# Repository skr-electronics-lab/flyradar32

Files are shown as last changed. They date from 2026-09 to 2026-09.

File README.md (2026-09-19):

# FlyRadar32

### Autonomous Desktop ADS-B Flight Radar and Avionics Ground Station

FlyRadar32 is a standalone desktop aviation instrument powered by an ESP32 dual-core microcontroller and a 1.8-inch ST7735 SPI display. It aggregates real-time ADS-B transponder telemetry from global flight tracking networks, computes spatial trajectories, and renders a sweeping 60 FPS PPI (Plan Position Indicator) radar display without requiring an external computer or cloud intermediary.

<div align="center">






<p align="center">
  <a href="https://ko-fi.com/skrelectronicslab">
    Support on Ko-fi
  </a>
</p>

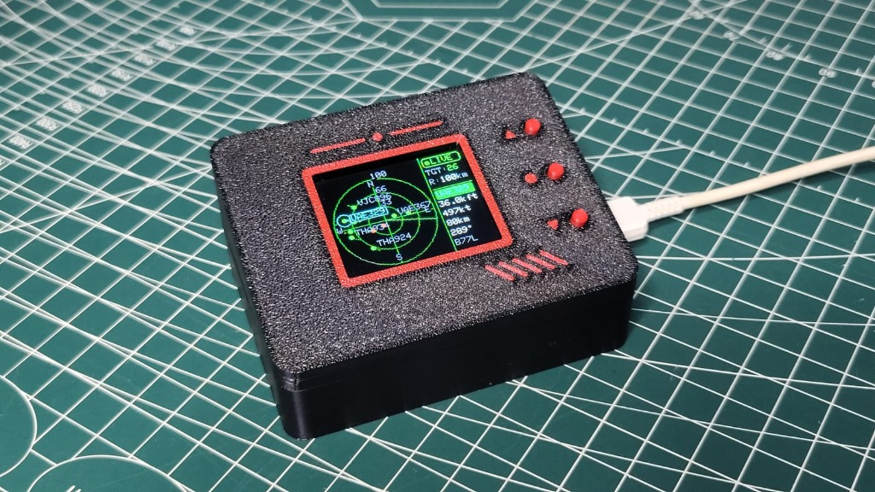
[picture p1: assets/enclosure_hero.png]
FlyRadar32 Desktop Radar Console


</div>

---

## Table of Contents

- [System Architecture](#system-architecture)
- [Key Features](#key-features)
- [Hardware Specification and BOM](#hardware-specification-and-bom)
- [Circuit Diagram and Physical Prototype](#circuit-diagram-and-physical-prototype)
- [3D Printable Enclosure](#3d-printable-enclosure)
- [Embedded Web Dashboard](#embedded-web-dashboard)
- [Firmware Build and Deployment](#firmware-build-and-deployment)
- [First Boot and Captive Portal](#first-boot-and-captive-portal)
- [REST API Specification](#rest-api-specification)
- [GitHub Repository Topics](#github-repository-topics)
- [Author and Support](#author-and-support)
- [License](#license)

---

## System Architecture

FlyRadar32 segregates workloads across both symmetric Xtensa LX6 CPU cores using FreeRTOS tasks to guarantee deterministic screen refresh rates regardless of network latency:

<div align="center">

FlyRadar32 System Architecture

</div>

- **Core 0 (Networking & Telemetry Pipeline):**
  Executes HTTP/TLS REST requests, handles JSON deserialization, runs the automated failover circuit breaker across ADS-B data providers, and serves the embedded web dashboard.
- **Core 1 (Real-Time Graphics Pipeline):**
  Drives the ST7735 display over high-speed SPI (27 MHz). Performs double-buffered polar coordinate projection, renders heading vectors and history trails, and samples tactile push buttons with state debounce logic.

---

## Key Features

- **Live Multi-Target ADS-B Tracking:** Decodes ICAO 24-bit transponder addresses, callsigns, barometric/geometric altitude, ground speed (knots), track heading (degrees), and vertical rate (feet/min).
- **Tri-Tier Provider Redundancy:** Integrates `airplanes.live`, `adsb.lol`, and `OpenSky Network`. An automated circuit breaker detects consecutive network timeouts (3 strikes) and applies a cooldown backoff to prevent API starvation.
- **Precision Polar Radar Graphics:** Plan Position Indicator (PPI) with a continuous sweep line, concentric range rings (5, 10, 25, 50, 100 NM), cardinal compass headings, and target history breadcrumb trails.
- **Self-Contained Embedded Web Dashboard:** Zero-dependency responsive control panel served directly from ESP32 flash with live radar maps, target flight board, weather telemetry, coordinate calibration, Wi-Fi management, and display preferences.
- **Captive Portal Field Deployment:** Launches an autonomous setup Access Point (`FlyRadar32-XXXX`) if configured Wi-Fi credentials fail, automatically redirecting connected mobile or desktop browsers to the provisioning console.
- **Non-Volatile Configuration Memory:** Home coordinates, range limits, display brightness, screen themes, and API credentials persist across power cycles in ESP32 Non-Volatile Storage (NVS).

---

## Hardware Specification and BOM

| Component | Specification | Quantity | Reference Source |
|---|---|---|---|
| Microcontroller | ESP32-WROOM-32 (30-Pin DevKit, 4MB Flash) | 1 | Espressif Systems |
| Display | 1.8" TFT ST7735 (128x160 RGB, 4-Wire SPI) | 1 | Black-Tab / Red-Tab |
| User Input | 6x6x3.8mm Momentary Tactile Push Buttons | 3 | SPST Through-Hole |
| Enclosure | 3-Piece Precision FDM Chassis (PETG / PLA) | 1 Set | [enclosure/](enclosure/) |
| Power Source | 5V USB-C or Micro-USB (500mA minimum) | 1 | Standard USB Port |

---

## Circuit Diagram and Physical Prototype

### Live Hardware Prototype

<div align="center">

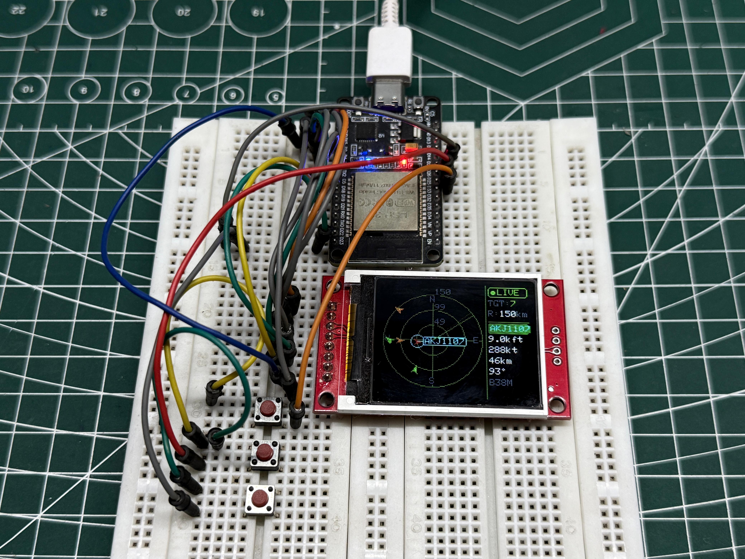
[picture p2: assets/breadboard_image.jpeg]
FlyRadar32 Live Breadboard Prototype


*FlyRadar32 standalone hardware tracking active aviation target AKJ1107 (Boeing 737 MAX 8) on a 1.8" ST7735 SPI display.*

</div>

### Schematic Circuit Diagram

<div align="center">

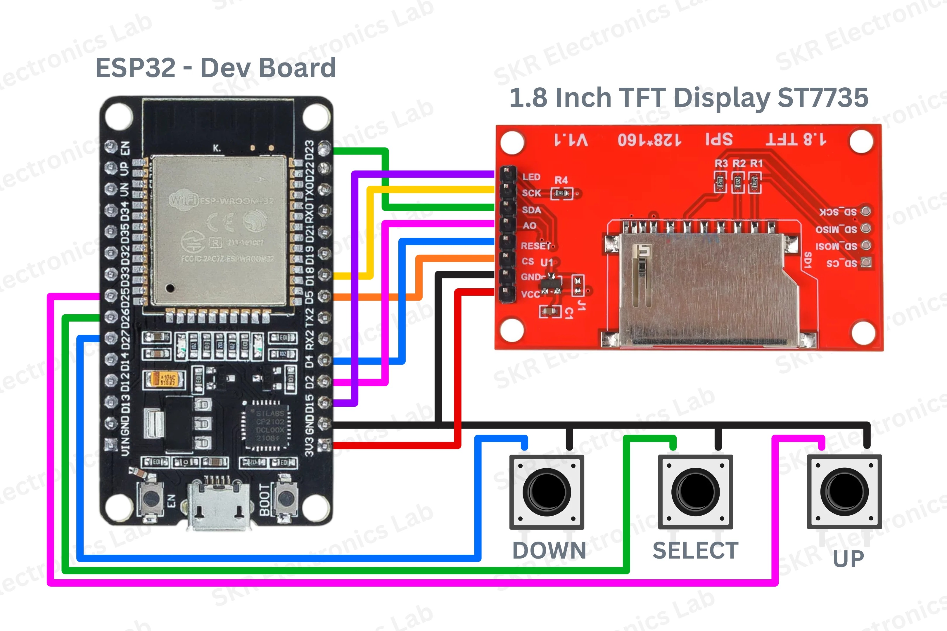
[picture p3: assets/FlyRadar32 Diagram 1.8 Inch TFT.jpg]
FlyRadar32 Circuit Diagram


</div>

### Pinout Mapping

| Function | ESP32 GPIO | Peripheral Pin | Description |
|---|---|---|---|
| Display SCLK | GPIO 18 | SCK / CLK | Hardware VSPI Clock (27 MHz) |
| Display MOSI | GPIO 23 | SDA / DIN | Hardware VSPI Data Line |
| Display CS | GPIO 5 | CS | Chip Select (Active Low) |
| Display DC | GPIO 2 | DC / AO | Data / Command Select |
| Display RST | GPIO 4 | RES / RESET | Hardware Reset Pulse |
| Display BL | GPIO 15 | BL / LED | Hardware LEDC PWM Backlight Dimming (5,000 Hz, 8-Bit) |
| Display VCC | VIN (5V) / 3V3 | VCC | Display Logic and Backlight Supply |
| Display GND | GND | GND | Common Circuit Ground |
| Button UP | GPIO 25 | Pin 1 to GPIO, Pin 2 to GND | Cycle target aircraft / Long-press: Live Weather |
| Button DOWN | GPIO 26 | Pin 1 to GPIO, Pin 2 to GND | Cycle target aircraft / Long-press: Flight List |
| Button SELECT | GPIO 27 | Pin 1 to GPIO, Pin 2 to GND | Short: Flight Detail / Long: Settings / Dual UP+DOWN: Weather |

> **Strapping Pin Notice:** Do not connect pull-down loads or switches to GPIO 0, GPIO 12, or GPIO 15 that force unexpected boot logic levels.

---

## 3D Printable Enclosure

The desktop enclosure features an ergonomic 15-degree instrument slant, internal snap-latch joints, zero exterior screws, and anti-fallout button actuators.

All 3D models and print documentation are located in the [enclosure/](enclosure/) directory:

<div align="center">

| Internal Seating | Transparent Assembly |
|:---:|:---:|
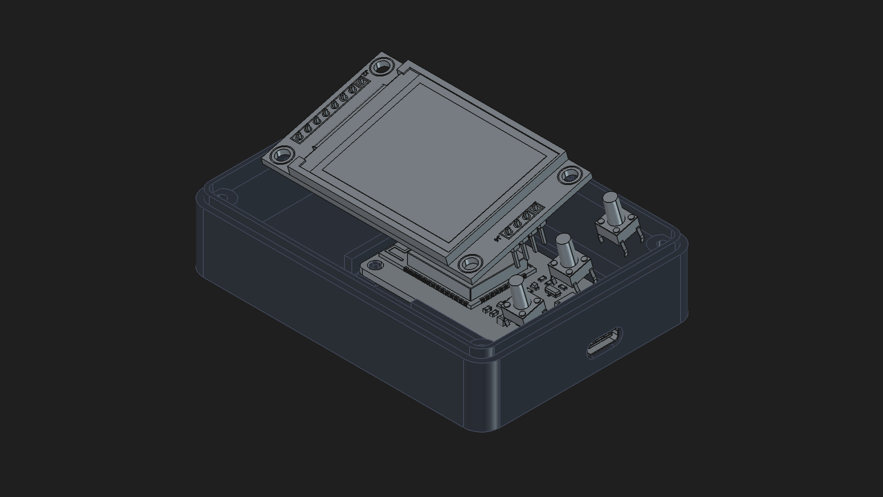
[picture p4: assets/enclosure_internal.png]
Internal Seating
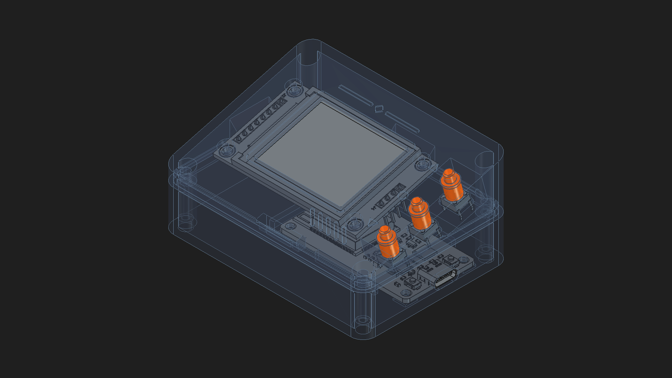
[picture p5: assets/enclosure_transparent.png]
Transparent Assembly
|  |  |

</div>

### Printable Files

- [`enclosure/flyradar32_shell.stl`](enclosure/flyradar32_shell.stl) — Bottom chassis with ESP32 board rails and USB collar.
- [`enclosure/flyradar32_lid.stl`](enclosure/flyradar32_lid.stl) — Top bezel with 15° instrument tilt and display aperture.
- [`enclosure/flyradar32_button_caps.stl`](enclosure/flyradar32_button_caps.stl) — 3x tactile actuator keycaps with retention lips.
- [`enclosure/FlyRadar32_Enclosure.FCStd`](enclosure/FlyRadar32_Enclosure.FCStd) — Master parametric CAD file (FreeCAD).

### Print Parameters

- **Layer Height:** 0.20 mm (0.16 mm for keycaps)
- **Walls / Perimeters:** 3
- **Infill:** 20% Gyroid or Grid
- **Material:** PETG or PLA
- **Supports:** None required (All geometries self-supporting <= 45°)

---

## Embedded Web Dashboard

FlyRadar32 serves an asynchronous, zero-dependency web interface directly from internal LittleFS flash storage.

<div align="center">

| Live Radar Scope | Air Traffic Flight Board |
|:---:|:---:|
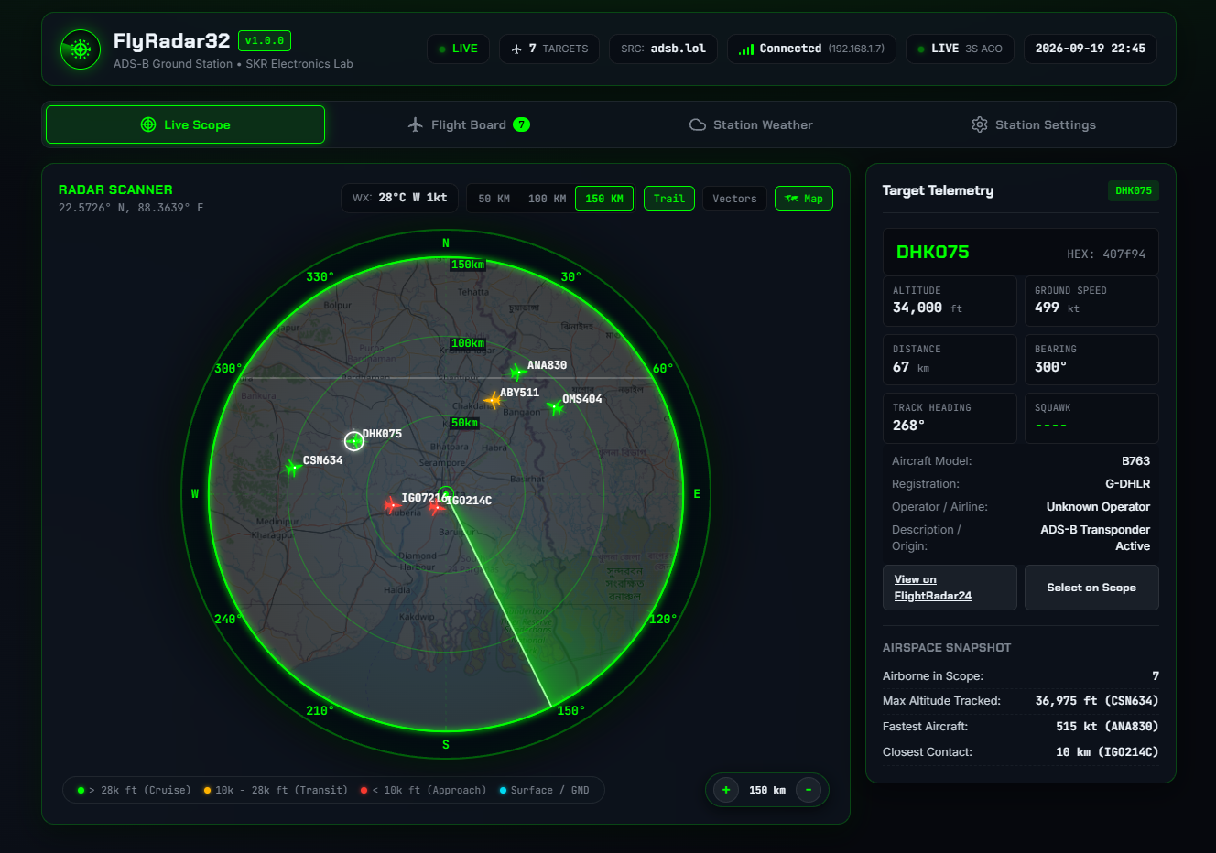
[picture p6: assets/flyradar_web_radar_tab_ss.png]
Live Radar Scope
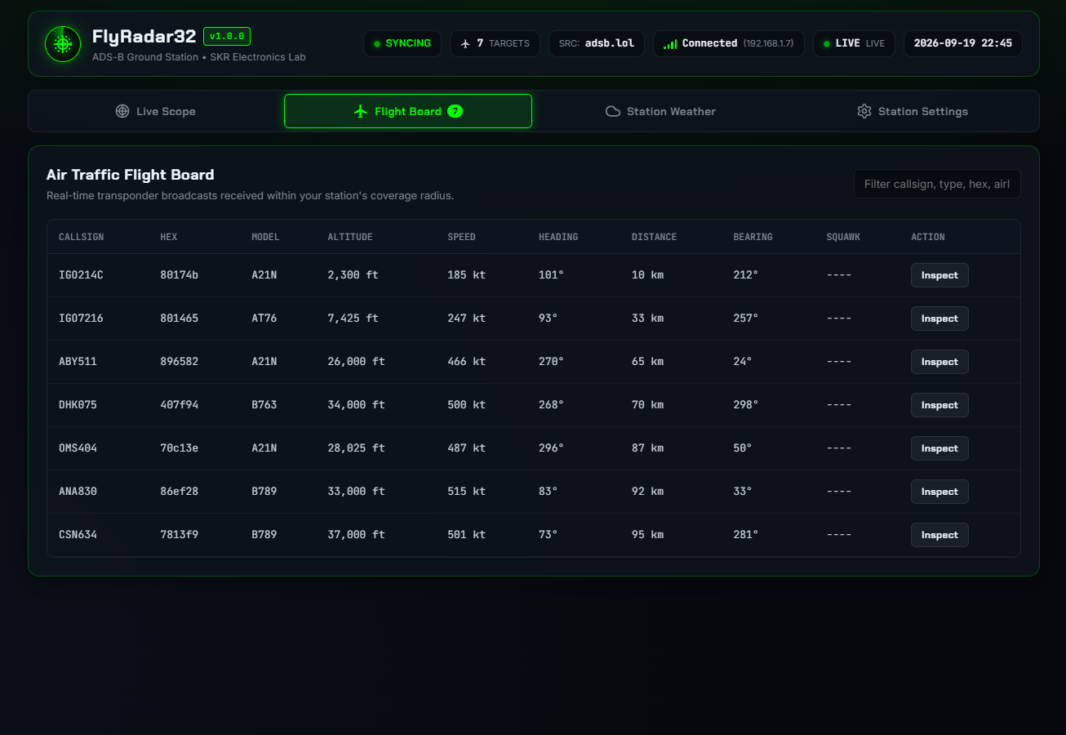
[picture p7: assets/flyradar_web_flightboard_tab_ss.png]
Air Traffic Flight Board
|  |  |

| Station Weather | Station Settings |
|:---:|:---:|
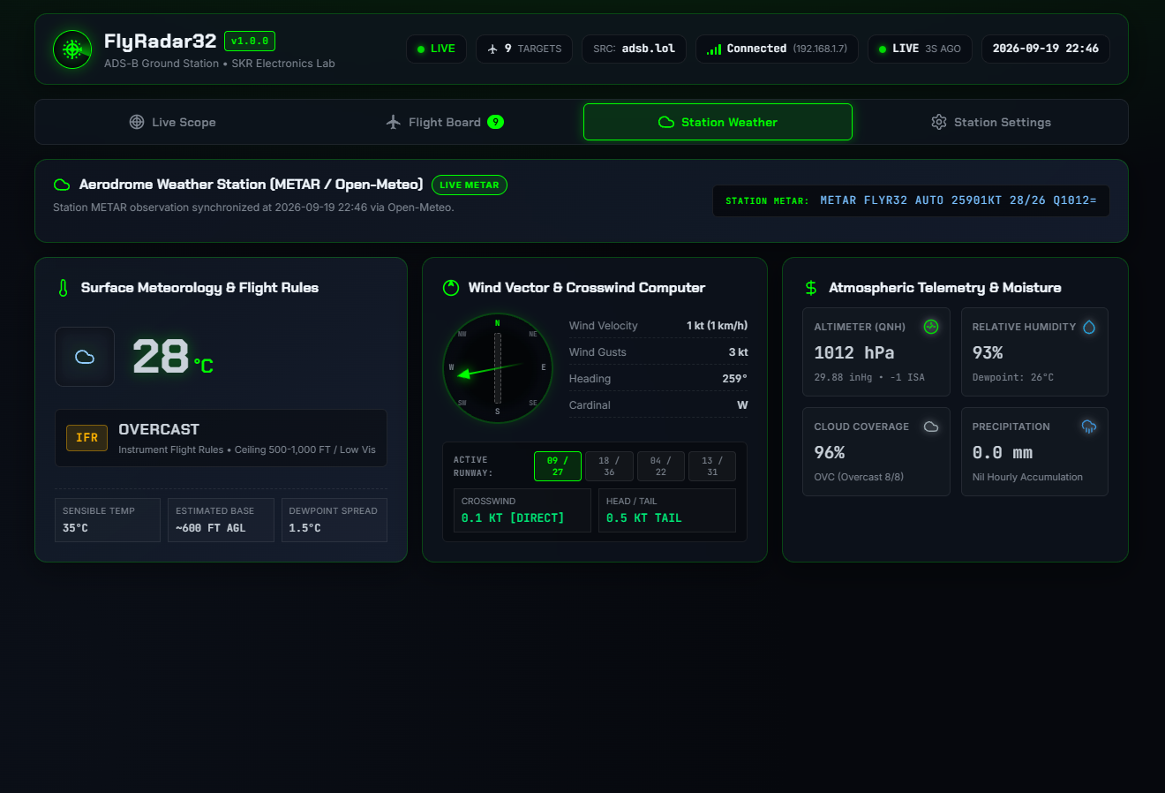
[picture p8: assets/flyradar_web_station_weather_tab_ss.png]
Station Weather
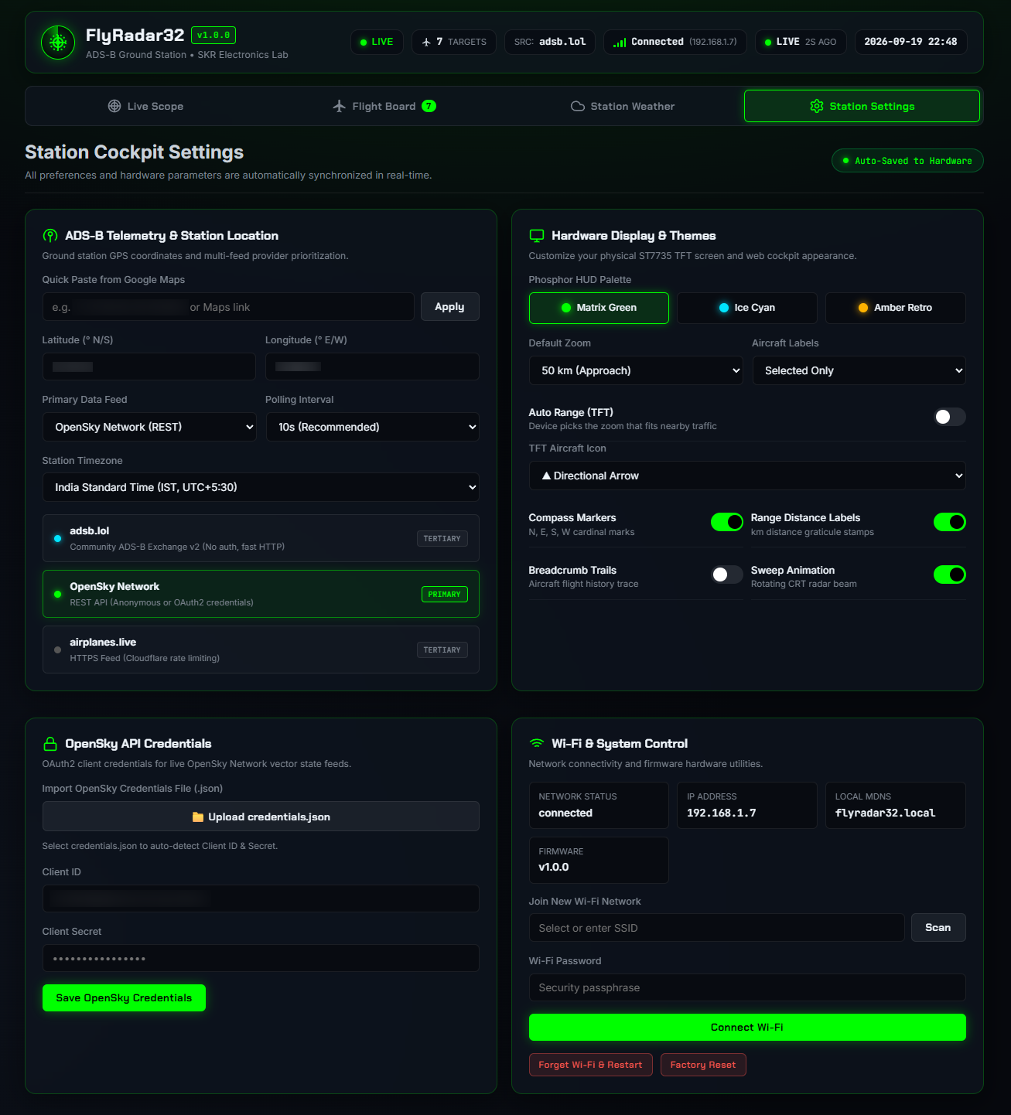
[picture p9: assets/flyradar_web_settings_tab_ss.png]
Station Settings
|  |  |

</div>

- **Live Scope:** Real-time canvas radar scope displaying aircraft positions, heading vectors, altitude color bands, and range scaling.
- **Flight Board:** Tabular air traffic ledger with callsign search, hex code, altitude, speed, heading, and distance sorting.
- **Station Weather:** Live local barometric and meteorological telemetry report.
- **Station Settings:** Coordinate calibration, Wi-Fi network switching, refresh intervals, and display themes.

---

## Firmware Build and Deployment

PlatformIO automatically compresses web assets from `data/` into Gzip byte arrays during compilation.

```bash
# Clone the repository
git clone https://github.com/skrelectronicslab/flyradar32.git
cd flyradar32

# Compile firmware
pio run

# Flash firmware over USB
pio run --target upload

# Open serial telemetry monitor (115200 baud)
pio run --target monitor
```

---

## First Boot and Captive Portal

1. **Power-On:** If no Wi-Fi credentials are saved, the device hosts an Access Point named `FlyRadar32-XXXX` (passphrase: `radar1234`).
2. **Setup Portal:** Connect to the AP from a mobile phone or laptop. The browser automatically navigates to `http://192.168.4.1`.
3. **Configure:** Select your Wi-Fi SSID, enter the password, and set your observer coordinates.
4. **Operation:** The device connects to your network, displays its assigned IP address on the screen, and starts tracking live aircraft.

---

## REST API Specification

FlyRadar32 exposes a lightweight HTTP REST API for integration into Home Assistant, Node-RED, or custom telemetry dashboards:

| Method | Endpoint | Description | Sample Output / Payload |
|---|---|---|---|
| `GET` | `/api/status` | Current radar telemetry and aircraft list | `{"uptime":3600,"wifi":"OK","aircraft_count":12,"targets":[...]}` |
| `GET` | `/api/config` | Read active system parameters | `{"lat":37.7749,"lon":-122.4194,"range":25,"theme":0}` |
| `POST` | `/api/config` | Update system parameters | `{"lat":51.5074,"lon":-0.1278,"range":50}` |
| `GET` | `/api/wifi/scan`| Scan for 2.4GHz Wi-Fi networks | `[{"ssid":"HomeNet","rssi":-58,"secure":true}]` |
| `POST` | `/api/wifi/connect`| Save Wi-Fi credentials and connect | `{"ssid":"HomeNet","password":"secretpassword"}` |
| `POST` | `/api/restart` | Issue software reboot | `{"status":"restarting"}` |

---

## GitHub Repository Topics

Add the following tags in your GitHub repository settings under **About -> Topics**:

```text
esp32, ads-b, flight-radar, aviation, radar-display, st7735, freertos, platformio, embedded-systems, cplusplus, 3d-printing, freecad, opensky-network, iot, open-source-hardware
```

---

## Author and Support

FlyRadar32 is designed and developed by **Raihan (SK Raihan)**.

- **Organization:** SKR Electronics Lab / SKR Projects Hub
- **YouTube:** [@skr_electronics_lab](https://youtube.com/@skr_electronics_lab)
- **Instagram:** [@skr_electronics_lab](https://instagram.com/skr_electronics_lab)
- **X (Twitter):** [@skrelectronics](https://twitter.com/skrelectronics)
- **Email:** `skrelectronicslab@gmail.com`

If you enjoy this open-source project and want to support ongoing development, consider buying a coffee on Ko-fi:

<div align="center">

Support on Ko-fi (https://ko-fi.com/skrelectronicslab)

</div>

---

## License
 
 This project is licensed under the [Creative Commons Attribution-NonCommercial-NoDerivatives 4.0 International License (CC BY-NC-ND 4.0)](LICENSE).
 
 - **Personal & Educational Use:** Free to build, 3D-print, flash firmware, and operate physical FlyRadar32 units for personal non-commercial hobbyist use.
 - **No Rebranding / No Derivatives:** You may not modify the design, source code, or CAD models and redistribute them claiming them as your own original work.
 - **Non-Commercial:** Commercial manufacturing, sale of pre-assembled units, paid kits, or commercial monetization without prior explicit written authorization is strictly prohibited.
 - **Attribution:** Creator credit to **SK Raihan (SKR Electronics Lab)** must be preserved on all forks and physical builds.

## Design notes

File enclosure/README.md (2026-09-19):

# FlyRadar32 3D Printable Enclosure

Snap-fit desktop console enclosure for the FlyRadar32 standalone ADS-B ground station.

---

<div align="center">

FlyRadar32 3D Printable Console

</div>

---

## Printable Files

The complete enclosure consists of three printable STL files designed for zero-support FDM printing:

| File | Description | Material | Infill | Supports |
|---|---|---|---|---|
| [`flyradar32_shell.stl`](flyradar32_shell.stl) | Bottom chassis with ESP32 mounting rails & USB port | PLA / PETG | 20% | None |
| [`flyradar32_lid.stl`](flyradar32_lid.stl) | Top bezel with 15° desktop tilt & display frame | PLA / PETG | 20% | None |
| [`flyradar32_button_caps.stl`](flyradar32_button_caps.stl) | 3x tactile button actuator keycaps | PLA / PETG | 100% | None |

Master CAD Source: [`FlyRadar32_Enclosure.FCStd`](FlyRadar32_Enclosure.FCStd) (FreeCAD).

---

## Hardware Fit & Assembly

<div align="center">

| Internal Seating | Transparent CAD Assembly |
|:---:|:---:|
| Internal Seating | Transparent Assembly |

</div>

### Quick Print Settings

- **Layer Height:** 0.20 mm (0.16 mm for keycaps)
- **Perimeters / Walls:** 3
- **Infill:** 20% Gyroid or Grid
- **Supports:** None needed (all overhangs <= 45°)
- **Orientation:**
  - `flyradar32_shell.stl`: Flat on bottom
  - `flyradar32_lid.stl`: Face-down on print bed
  - `flyradar32_button_caps.stl`: Flange down

### Assembly

1. Drop the 3 button keycaps into the underside of the lid through the switch holes (the retaining flanges keep them from falling out).
2. Seat the 1.8" ST7735 display into the lid frame.
3. Slide the ESP32 into the bottom shell rails and push onto the 4 alignment pins.
4. Snap the lid onto the bottom shell — the internal snap clips lock firmly without screws or glue.

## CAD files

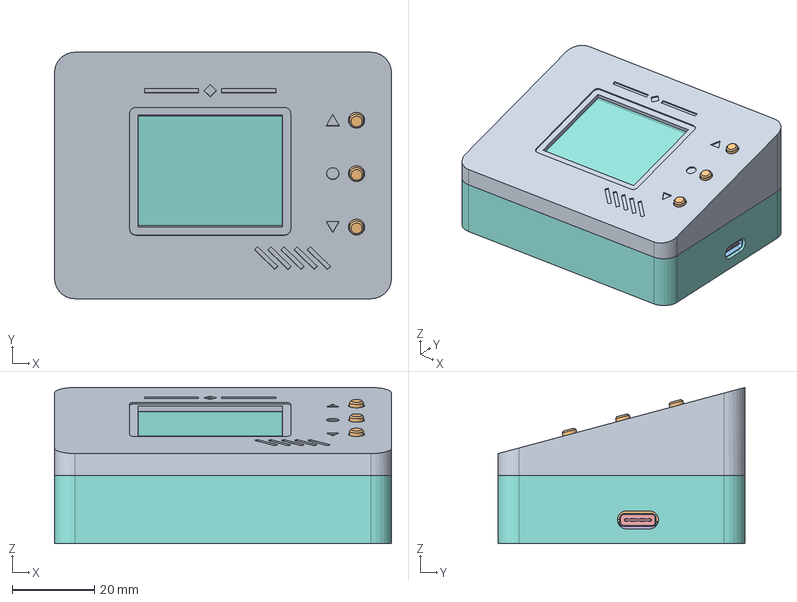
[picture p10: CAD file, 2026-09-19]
enclosure/FlyRadar32_Enclosure.FCStd
82.0 x 60.0 x 38.0 mm
esp32_Wroom_30pins_C-Type
esp32_Wroom_30pins_C-Type001
esp32_Wroom_30pins_C-Type002
esp32_Wroom_30pins_C-Type003
esp32_Wroom_30pins_C-Type004
esp32_Wroom_30pins_C-Type005
esp32_Wroom_30pins_C-Type006
esp32_Wroom_30pins_C-Type007
esp32_Wroom_30pins_C-Type008
esp32_Wroom_30pins_C-Type009
esp32_Wroom_30pins_C-Type010
esp32_Wroom_30pins_C-Type011
esp32_Wroom_30pins_C-Type012
esp32_Wroom_30pins_C-Type013
esp32_Wroom_30pins_C-Type014
esp32_Wroom_30pins_C-Type015
esp32_Wroom_30pins_C-Type016
esp32_Wroom_30pins_C-Type017
esp32_Wroom_30pins_C-Type018
esp32_Wroom_30pins_C-Type019
esp32_Wroom_30pins_C-Type020
esp32_Wroom_30pins_C-Type021
esp32_Wroom_30pins_C-Type022
esp32_Wroom_30pins_C-Type023
esp32_Wroom_30pins_C-Type024
esp32_Wroom_30pins_C-Type025
esp32_Wroom_30pins_C-Type026
esp32_Wroom_30pins_C-Type027
esp32_Wroom_30pins_C-Type028
esp32_Wroom_30pins_C-Type029
esp32_Wroom_30pins_C-Type030
esp32_Wroom_30pins_C-Type031
esp32_Wroom_30pins_C-Type032
esp32_Wroom_30pins_C-Type033
esp32_Wroom_30pins_C-Type034
esp32_Wroom_30pins_C-Type035
esp32_Wroom_30pins_C-Type036
esp32_Wroom_30pins_C-Type037
esp32_Wroom_30pins_C-Type038
esp32_Wroom_30pins_C-Type039
esp32_Wroom_30pins_C-Type040
esp32_Wroom_30pins_C-Type041
esp32_Wroom_30pins_C-Type042
esp32_Wroom_30pins_C-Type043
esp32_Wroom_30pins_C-Type044
esp32_Wroom_30pins_C-Type045
esp32_Wroom_30pins_C-Type046
esp32_Wroom_30pins_C-Type047
esp32_Wroom_30pins_C-Type048
esp32_Wroom_30pins_C-Type049
esp32_Wroom_30pins_C-Type050
esp32_Wroom_30pins_C-Type051
esp32_Wroom_30pins_C-Type052
esp32_Wroom_30pins_C-Type053
esp32_Wroom_30pins_C-Type054
esp32_Wroom_30pins_C-Type055
esp32_Wroom_30pins_C-Type056
esp32_Wroom_30pins_C-Type057
esp32_Wroom_30pins_C-Type058
esp32_Wroom_30pins_C-Type059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

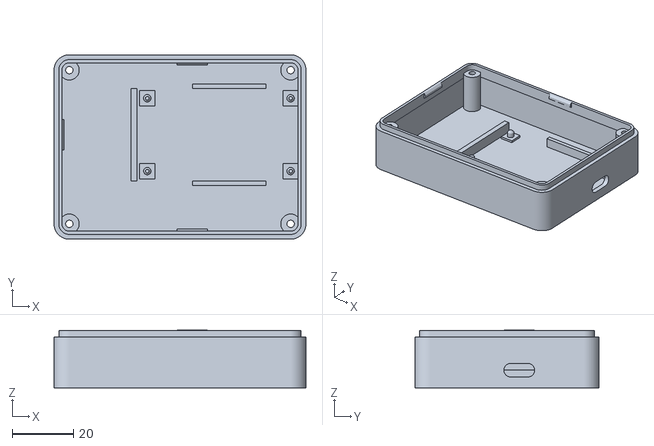
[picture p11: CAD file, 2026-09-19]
enclosure/flyradar32_shell.stl
82.0 x 60.0 x 18.8

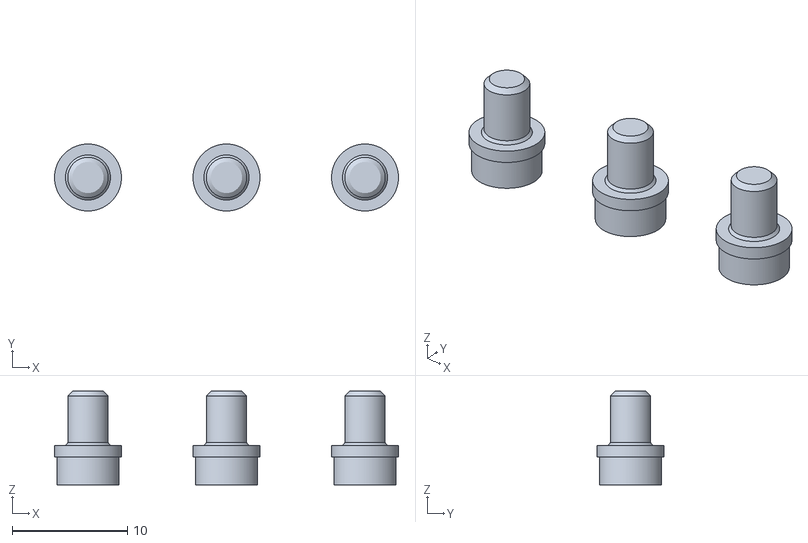
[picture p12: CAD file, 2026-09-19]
enclosure/flyradar32_button_caps.stl
29.8 x 5.80 x 8.10

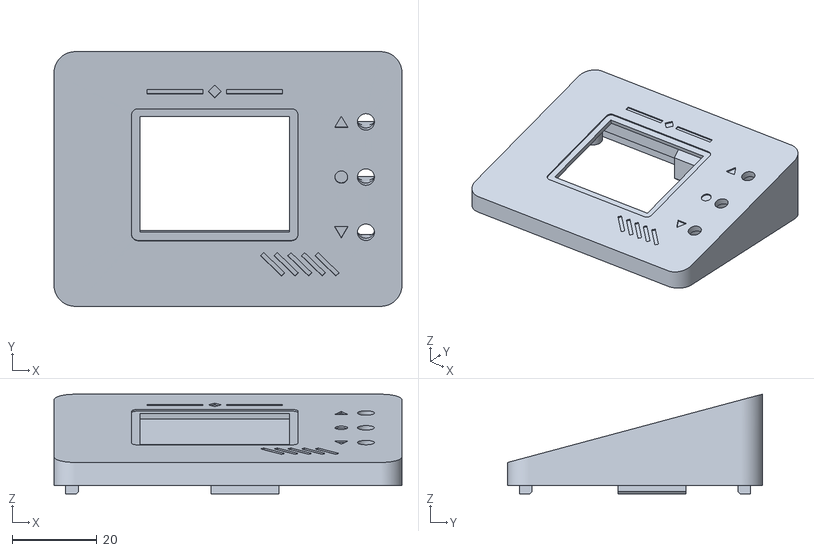
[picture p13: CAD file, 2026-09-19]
enclosure/flyradar32_lid.stl
82.0 x 60.0 x 23.5

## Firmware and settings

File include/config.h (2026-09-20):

#pragma once
#include <Arduino.h>

// ============================================================
//  DISPLAY PINS (ST7735, 128x160 native panel)
//  6-pin: SCL→18, SDA→23, RES→4, DC→2, CS→5, BL→15
// ============================================================
#define TFT_CS    5
#define TFT_RST   4
#define TFT_DC    2
#define TFT_BLK   15
#define TFT_SCLK  18
#define TFT_MOSI  23

// ============================================================
//  ORIENTATION
//  ------------------------------------------------------------
//  The ST7735 panel is *physically* 128 px wide x 160 px tall
//  (that native size is what TFT_WIDTH/TFT_HEIGHT in
//  platformio.ini describe, and must never change — it's what
//  the controller's init sequence was written for).
//
//  Landscape mode is achieved purely by ROTATING that native
//  panel with TFT_ROTATION below. TFT_eSPI swaps width/height
//  for you once you rotate — so from this point on, SCREEN_W /
//  SCREEN_H below are the *logical* (already-rotated) canvas
//  size, and EVERYTHING in the firmware (LVGL resolution, the
//  TFT_eSprite radar canvas, and every layout constant) is
//  derived from these two numbers and nothing else. That is
//  the fix for the old "right side cut off ~40%" bug: previously
//  SCREEN_W/SCREEN_H stayed at the portrait 128x160 values while
//  only the physical rotation changed, so LVGL kept thinking the
//  panel was 128 wide and never drew (160-128)=32 of the 160
//  physical columns, AND the radar sprite was allocated
//  128(w) x 160(h) and pushed onto a panel that was now
//  addressed as 160(w) x 128(h) — a shape mismatch that made
//  the driver's address window wrap/clip, which combined with
//  the old circle being centered on x=64 of what is now the
//  left ~40% of a 160-wide panel, is exactly why it looked like
//  "40% cut off on the right". Fixing SCREEN_W/SCREEN_H to the
//  true rotated size and re-deriving every constant from them
//  removes the mismatch entirely.
//
//  If the image comes up mirrored/upside-down for your specific
//  panel wiring, change TFT_ROTATION to 3 (the only other valid
//  landscape rotation for ST7735) — nothing else needs to change.
// ============================================================
#define TFT_ROTATION 3

#define SCREEN_W  160
#define SCREEN_H  128

// ============================================================
//  BUTTON PINS  (deliberately NOT GPIO0 - that pin is the boot-mode
//  strap; holding it low at power-on/reset forces the download
//  bootloader instead of your app)
// ============================================================
#define BTN_UP      25
#define BTN_DOWN    27
#define BTN_SELECT  26

#define LONG_PRESS_MS   700
#define DEBOUNCE_MS     20

// Watchdog: the Arduino core's Task WDT already exists (5 s idle timeout);
// loop() subscribes to it, so a hung loop triggers a clean reboot.
// (esp_task_wdt_reset() runs at the top of every loop() pass.)
#define WDT_TIMEOUT_S 15

// Backlight PWM runs on GPIO15 (TFT_BLK). If the screen dims INVERTED
// (25% looks brighter than 100%), flip BACKLIGHT_ACTIVE_LOW in
// src/radar_display.cpp. If brightness changes nothing at all, your
// module's BL pin is probably tied to 3.3V / not wired to GPIO15.

// ============================================================
//  RADAR SCREEN LAYOUT (160x128 landscape)
//  ------------------------------------------------------------
//  Math: the radar circle is placed in the left region of the
//  panel, leaving a fixed-width sidebar on the right for status
//  text (so nothing ever overlaps the circle). The sidebar width
//  is sized around the built-in 6px/char GLCD font so a 7-char
//  flight callsign (e.g. "IG06313") always fits with margin:
//    7 chars * 6px = 42px text + 4px left pad + 2px right margin
//    => SIDEBAR_W = 48 is the minimum that never overflows.
//
//  Everything else is derived so it can never overflow the
//  160x128 canvas:
//
//    SIDEBAR_W = 48                          (right info column)
//    RADAR_ZONE_W = SCREEN_W - SIDEBAR_W = 112
//    CX = RADAR_ZONE_W / 2 = 56              (center of the zone)
//    CY = SCREEN_H / 2 = 64                  (vertical center)
//    RADAR_R = CX - MARGIN(4) = 52           (horizontal is the
//              tighter constraint here, so it sets the radius)
//
//  Circle extents: x∈[4,108] (4px clear of the 0 and 112 edges),
//  y∈[12,116] (12px clear of the 0 and 128 edges) — fully on
//  screen with margin on every side, at every rotation.
// ============================================================
#define SIDEBAR_W     48
#define RADAR_ZONE_W  (SCREEN_W - SIDEBAR_W)   // 112
#define CX            (RADAR_ZONE_W / 2)       // 56
#define CY            (SCREEN_H / 2)           // 64
#define RADAR_R       52
#define SIDEBAR_X     (SCREEN_W - SIDEBAR_W)   // 112 (divider line x)
#define SIDEBAR_CHARS_MAX 7                    // longest label safe in the sidebar column

// ============================================================
//  COLORS (RGB565) — base/legacy palette (Theme 0 uses these)
// ============================================================
#define CLR_BG       0x0000
#define CLR_GRID     0x03E0
#define CLR_SWEEP    0x07E0
#define CLR_PLANE    0xF800
#define CLR_PLANE_HI 0xFFE0   // yellow - low altitude
#define CLR_PLANE_MD 0xFD20   // orange - mid altitude
#define CLR_TEXT     0xFFFF
#define CLR_DIM      0x7BEF
#define CLR_SEL      0x07FF   // cyan selection ring
#define CLR_ERR      0xF800

#define THEME_COUNT 3

// ============================================================
//  API PROVIDERS
// ============================================================
#define PROVIDER_OPENSKY        0
#define PROVIDER_ADSB_LOL       1
#define PROVIDER_AIRPLANES_LIVE 2
#define PROVIDER_COUNT          3

// ============================================================
//  AIRCRAFT DATA
// ============================================================
#define MAX_PLANES 50

// Trail (breadcrumb) history — 25 slots * (5 fixes * 8 bytes + 16 B) ≈ 1.1 KB
#define TRAIL_LEN 5

struct AircraftPoint {
    bool  valid;
    char  icaoHex[8];
    char  flight[10];
    char  aircraftType[8];
    char  desc[32];
    char  registration[12];
    char  operatorName[32];
    char  squawk[5];
    float distanceKm;
    float bearingDeg;
    int   altitudeFt;
    float speedKt;
    float trackDeg;
    bool  onGround;
};

// Icon styles selectable in settings
#define AIRCRAFT_ICON_DOT      0
#define AIRCRAFT_ICON_ARROW    1
#define AIRCRAFT_ICON_PLANE    2
#define AIRCRAFT_ICON_COUNT    3

// ============================================================
//  NVS / PREFERENCES NAMESPACES & KEYS
// ============================================================
#define NVS_NS_WIFI     "wifi"
#define NVS_NS_LOC      "loc"
#define NVS_NS_API      "api"
#define NVS_NS_DISPLAY  "display"

// ============================================================
//  FIRMWARE INFO
// ============================================================
#define FW_NAME     "FlyRadar32"
#define FW_VERSION  "1.0.0"
#define FW_BRAND    "by SKR Electronics Lab"
#define MDNS_NAME   "flyradar32"

// ============================================================
//  DEFAULTS
// ============================================================
#define DEFAULT_LAT  22.5726
#define DEFAULT_LON  88.3639
#define AP_SSID_PREFIX "FlyRadar32-"
#define AP_PASSWORD    "radar1234"
#define WEB_CONFIG_PORT 80

// POSIX TZ string for NTP local time (change to your zone, e.g. "EST5EDT,M3.2.0,M11.1.0")
#define DEFAULT_TZ "IST-5:30"

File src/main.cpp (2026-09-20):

#include <Arduino.h>
#include "config.h"
#include "storage.h"
#include "buttons.h"
#include "radar_display.h"
#include "wifi_manager.h"
#include "api_providers.h"
#include "webui.h"
#include <lvgl.h>

static AppScreen currentScreen = SCR_BOOT;

static AircraftPoint planes[MAX_PLANES];
static int planeCount = 0;

static int sweepAngle = 0;
static int selectedPlaneIndex = -1;
static int detailPlaneIndex = -1;
static char detailPlaneHex[8] = "";   // ICAO of the plane shown on the detail screen
static int detailScrollY = 0;
static int listSelectedIndex = 0;

static int settingsMainIndex = 0;
static int settingsMainScroll = 0;
static int settingsDisplayIndex = 0;
static int settingsLabelsIndex = 0;
static int settingsIconIndex = 0;
static int settingsProvidersIndex = 0;
static int settingsProvidersScroll = 0;

static unsigned long lastPeriodicRefreshMs = 0;
static unsigned long lastDrawMs = 0;
static unsigned long wifiConnectedScreenShownAt = 0;

static const char* THEME_NAMES[THEME_COUNT] = {"GREEN", "CYAN", "AMBER"};

// ---------------------------------------------------------------
// Settings menu layout.
// ---------------------------------------------------------------
#define SETTINGS_MAIN_COUNT 17
static const char* settingsMainLabels[SETTINGS_MAIN_COUNT] = {
    "Radar Range",
    "Auto Range",
    "Brightness",
    "Animation",
    "Labels",
    "Aircraft Icon",
    "Theme",
    "Compass",
    "Range Labels",
    "Trail",
    "Data Providers",
    "Aircraft List",
    "Weather Report",
    "Refresh Now",
    "System Info",
    "Factory Reset",
    "Back to Radar"
};

#define SETTINGS_DISPLAY_COUNT 5
static const char* settingsDisplayLabels[SETTINGS_DISPLAY_COUNT] = {
    "50 km",
    "100 km",
    "150 km",
    "300 km",
    "Back"
};

#define SETTINGS_LABELS_COUNT 4
static const char* settingsLabelsLabels[SETTINGS_LABELS_COUNT] = {
    "Disabled",
    "Selected Only",
    "All Aircraft",
    "Back"
};

#define SETTINGS_ICON_COUNT 4
static const char* settingsIconLabels[SETTINGS_ICON_COUNT] = {
    "Dots",
    "Arrow",
    "Aeroplane",
    "Back"
};

#define SETTINGS_PROVIDERS_COUNT 4
static const char* settingsProvidersLabels[SETTINGS_PROVIDERS_COUNT] = {
    "OpenSky",
    "adsb.lol",
    "airplanes.live",
    "Back"
};

static int calcScrollOffset(int selected, int total, int visible) {
    if (total <= visible) return 0;
    if (selected < 0) return 0;
    if (selected >= total) return total - visible;
    int offset = selected - visible / 2;
    if (offset < 0) offset = 0;
    if (offset > total - visible) offset = total - visible;
    return offset;
}

// Effective display zoom index (0..2) for this cycle. When autoRange is on,
// pick the smallest fixed zoom that contains the 10th-closest valid aircraft,
// with 2-cycle hysteresis so traffic sitting near a boundary doesn't flap.
// planes[] must already be valid-filled (not necessarily bearing-sorted).
static int effectiveZoom() {
    AppSettings& s = Storage::settings();
    if (!s.autoRange) return s.zoomLevel;

    // distances of valid planes (insertion sort, we only need order)
    float d[MAX_PLANES];
    int n = 0;
    for (int i = 0; i < planeCount && n < MAX_PLANES; i++) {
        if (planes[i].valid) {
            int j = n++;
            while (j > 0 && d[j-1] > planes[i].distanceKm) { d[j] = d[j-1]; j--; }
            d[j] = planes[i].distanceKm;
        }
    }
    if (n == 0) return s.zoomLevel;

    float ref = d[n >= 10 ? 9 : n - 1];   // 10th closest, or closest if fewer
    int want = 0;
    while (want < (ApiProviders::ZOOM_LEVEL_COUNT - 1) && ref > ApiProviders::ZOOM_KM[want]) want++;

    static int lastWant = -1;
    static int stableCount = 0;
    static int applied = -1;  // -1 = uninitialised; set to saved zoom on first call
    if (applied < 0) applied = Storage::settings().zoomLevel;
    if (want == lastWant) {
        if (stableCount < 2) stableCount++;
        if (stableCount >= 2 && applied != want) applied = want;   // commit
    } else {
        stableCount = 0;
        lastWant = want;
    }
    return applied;
}

static void clampSelection() {
    if (planeCount == 0) { selectedPlaneIndex = -1; return; }

    float maxVisibleDist = ApiProviders::ZOOM_KM[effectiveZoom()];

    if (selectedPlaneIndex >= 0 && selectedPlaneIndex < planeCount) {
        if (!planes[selectedPlaneIndex].valid || planes[selectedPlaneIndex].distanceKm > maxVisibleDist) {
            selectedPlaneIndex = -1;
        }
    }

    if (selectedPlaneIndex < 0) {
        for (int i = 0; i < planeCount; i++) {
            if (planes[i].valid && planes[i].distanceKm <= maxVisibleDist) {
                selectedPlaneIndex = i;
                break;
            }
        }
    }
}

// Sort planes by compass bearing (N->E->S->W clockwise). Called once per
// new fetch so UP/DOWN walking the array = walking clockwise around the
// scope, and the plane list shows compass order too.
static void sortByBearing() {
    char anchorHex[8] = "";
    if (selectedPlaneIndex >= 0 && selectedPlaneIndex < planeCount) {
        strncpy(anchorHex, planes[selectedPlaneIndex].icaoHex, 7);
        anchorHex[7] = '\0';
    }
    for (int i = 1; i < planeCount; i++) {
        AircraftPoint key = planes[i];
        int j = i - 1;
        while (j >= 0 && planes[j].bearingDeg > key.bearingDeg) {
            planes[j + 1] = planes[j];
            j--;
        }
        planes[j + 1] = key;
    }
    // Re-anchor the cursor to the same aircraft it had selected
    if (anchorHex[0] != '\0') {
        selectedPlaneIndex = -1;
        for (int i = 0; i < planeCount; i++) {
            if (planes[i].valid && strncmp(planes[i].icaoHex, anchorHex, 7) == 0) {
                selectedPlaneIndex = i;
                break;
            }
        }
        if (selectedPlaneIndex < 0) clampSelection();
    }
    // Re-anchor detailPlaneIndex (shown on SCR_PLANE_DETAIL) by hex so
    // the detail card never shows the wrong aircraft after a sort.
    if (detailPlaneHex[0] != '\0') {
        detailPlaneIndex = -1;
        for (int i = 0; i < planeCount; i++) {
            if (planes[i].valid && strncmp(planes[i].icaoHex, detailPlaneHex, 7) == 0) {
                detailPlaneIndex = i;
                break;
            }
        }
    }
}

static void moveSelection(int delta) {
    if (planeCount == 0) { selectedPlaneIndex = -1; return; }
    
    float maxVisibleDist = ApiProviders::ZOOM_KM[effectiveZoom()];
    int startIdx = selectedPlaneIndex;
    if (startIdx < 0) startIdx = 0; // If nothing selected, start from 0

    int nextIdx = startIdx;
    for (int i = 0; i < planeCount; i++) {
        nextIdx = (nextIdx + delta + planeCount) % planeCount;
        if (planes[nextIdx].valid && planes[nextIdx].distanceKm <= maxVisibleDist) {
            selectedPlaneIndex = nextIdx;
            return;
        }
    }
    // If no valid planes in range, deselect
    selectedPlaneIndex = -1;
}

// Persists every field currently in AppSettings that belongs to the
// "display" NVS namespace. Centralized here so every settings toggle
// below only has to mutate `s` and call this one helper.
static void persistDisplay(AppSettings& s) {
    Storage::saveDisplay(s.zoomLevel, s.labelsMode, s.aircraftIcon, s.showSweepAnim,
                          s.theme, s.showCompass, s.showRangeLabels, s.showTrail, s.brightness);
}

static void handleRadarButtons(ButtonEvent ev, ButtonId which) {
    if (ev == BTN_EVENT_SHORT_PRESS) {
        if (which == BTN_ID_UP || which == BTN_ID_DOWN) {
            if (planeCount > 0) {
                moveSelection(which == BTN_ID_UP ? -1 : 1);
            }
        } else if (which == BTN_ID_SELECT) {
            if (selectedPlaneIndex >= 0) {
                detailPlaneIndex = selectedPlaneIndex;
                strncpy(detailPlaneHex, planes[selectedPlaneIndex].icaoHex, 7);
                detailPlaneHex[7] = '\0';
                detailScrollY = 0;
                currentScreen = SCR_PLANE_DETAIL;
            } else {
                currentScreen = SCR_WEATHER;
            }
        }
    } else if (ev == BTN_EVENT_REPEAT) {
        if ((which == BTN_ID_UP || which == BTN_ID_DOWN) && planeCount > 0) {
            moveSelection(which == BTN_ID_UP ? -1 : 1);
        }
    } else if (ev == BTN_EVENT_LONG_PRESS) {
        if (which == BTN_ID_SELECT) {
            settingsMainIndex = 0; settingsMainScroll = 0;
            currentScreen = SCR_SETTINGS_MAIN;
        } else if (which == BTN_ID_UP) {
            currentScreen = SCR_WEATHER;
        } else if (which == BTN_ID_DOWN) {
            listSelectedIndex = 0;
            currentScreen = SCR_PLANE_LIST;
        }
    } else if (ev == BTN_EVENT_DUAL_LONG_PRESS) {
        currentScreen = SCR_WEATHER;   // UP+DOWN held together
    }
}

static void handleDetailButtons(ButtonEvent ev, ButtonId which) {
    if (planeCount == 0) { currentScreen = SCR_RADAR; return; }
    if (ev == BTN_EVENT_SHORT_PRESS || ev == BTN_EVENT_REPEAT) {
        if (which == BTN_ID_UP) {
            detailScrollY = max(0, detailScrollY - 12);
        } else if (which == BTN_ID_DOWN) {
            detailScrollY = min(125, detailScrollY + 12);
        } else if (which == BTN_ID_SELECT && ev == BTN_EVENT_SHORT_PRESS) {
            selectedPlaneIndex = detailPlaneIndex;
            currentScreen = SCR_RADAR;
        }
    } else if (ev == BTN_EVENT_LONG_PRESS && which == BTN_ID_SELECT) {
        selectedPlaneIndex = detailPlaneIndex;
        currentScreen = SCR_RADAR;
    }
}

static void handleListButtons(ButtonEvent ev, ButtonId which) {
    if (planeCount <= 0) {
        listSelectedIndex = 0;
        if (which == BTN_ID_SELECT && (ev == BTN_EVENT_SHORT_PRESS || ev == BTN_EVENT_LONG_PRESS)) {
            currentScreen = SCR_RADAR;
        }
        return;
    }
    if (ev == BTN_EVENT_SHORT_PRESS) {
        if (which == BTN_ID_UP) listSelectedIndex = max(0, listSelectedIndex - 1);
        else if (which == BTN_ID_DOWN) listSelectedIndex = min(planeCount - 1, listSelectedIndex + 1);
        else if (which == BTN_ID_SELECT) {
            detailPlaneIndex = listSelectedIndex;
            strncpy(detailPlaneHex, planes[listSelectedIndex].icaoHex, 7);
            detailPlaneHex[7] = '\0';
            detailScrollY = 0;
            currentScreen = SCR_PLANE_DETAIL;
        }
    } else if (ev == BTN_EVENT_REPEAT) {
        if (which == BTN_ID_UP) listSelectedIndex = max(0, listSelectedIndex - 1);
        else if (which == BTN_ID_DOWN) listSelectedIndex = min(planeCount - 1, listSelectedIndex + 1);
    } else if (ev == BTN_EVENT_LONG_PRESS && which == BTN_ID_SELECT) {
        currentScreen = SCR_RADAR;
    }
}
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
void loop() {
    WifiManager::loop();

    if (currentScreen == SCR_WIFI_SETUP) {
        static bool setupScreenDrawn = false;
        static bool connectedScreenDrawn = false;
        static WifiState lastWs = (WifiState)-1;
        
        WifiState ws = WifiManager::getState();
        if (ws != lastWs) {
            lastWs = ws;
            if (ws != WIFI_STATE_CONNECTED) {
                setupScreenDrawn = false;
                connectedScreenDrawn = false;
            }
        }
        if (ws == WIFI_STATE_CONNECTED) {
            if (!connectedScreenDrawn) {
                RadarDisplay::showConnectedScreen(WifiManager::getStaIp());
                connectedScreenDrawn = true;
                wifiConnectedScreenShownAt = millis();
            }
            if (wifiConnectedScreenShownAt > 0 && millis() - wifiConnectedScreenShownAt > 2000) {
                currentScreen = SCR_RADAR;
                ApiProviders::requestRefresh();
            }
        } else {
            if (!setupScreenDrawn) {
                RadarDisplay::showWifiSetupScreen(WifiManager::getApSsid(), WifiManager::getApIp());
                setupScreenDrawn = true;
            }
        }
        
        lv_timer_handler();
        delay(20);
        return;
    }

    ButtonId which;
    ButtonEvent ev = Buttons::poll(which);
    if (ev != BTN_EVENT_NONE) {
        switch (currentScreen) {
            case SCR_RADAR:                handleRadarButtons(ev, which); break;
            case SCR_PLANE_DETAIL:         handleDetailButtons(ev, which); break;
            case SCR_PLANE_LIST:           handleListButtons(ev, which); break;
            case SCR_WEATHER:
                // any SELECT press (short or long) returns to the radar
                if (which == BTN_ID_SELECT) currentScreen = SCR_RADAR;
                else if (which == BTN_ID_UP || which == BTN_ID_DOWN) {
                    RadarDisplay::toggleWeatherPage();
                }
                break;
            case SCR_SETTINGS_MAIN:
            case SCR_SETTINGS_DISPLAY:
            case SCR_SETTINGS_BRIGHTNESS:
            case SCR_SETTINGS_LABELS:
            case SCR_SETTINGS_ICON:
            case SCR_SETTINGS_PROVIDERS:
            case SCR_SYSTEM_INFO:
            case SCR_FACTORY_RESET_CONFIRM: handleSettingsButtons(ev, which); break;
            default: break;
        }
    }

    AppSettings& s = Storage::settings();

    uint32_t intervalMs = (s.refreshInterval < 10 ? 10 : s.refreshInterval) * 1000UL;
    if (millis() - lastPeriodicRefreshMs > intervalMs) {
        lastPeriodicRefreshMs = millis();
        ApiProviders::requestRefresh();
    }

    if (millis() - lastDrawMs >= 30) {
        lastDrawMs = millis();

        ApiProviders::getLatest(planes, planeCount);
        // New fetch arrived? Sort by compass bearing (once) so cursor/list
        // walk clockwise from here on.
        static unsigned long lastSortedSuccessMs = 0;
        ApiProviders::Status pst = ApiProviders::getStatus();
        if (planeCount > 0 && pst.lastSuccessMs != 0 && pst.lastSuccessMs != lastSortedSuccessMs) {
            lastSortedSuccessMs = pst.lastSuccessMs;
            sortByBearing();
        }
        RadarDisplay::sampleTrailHistory(planes, planeCount);
        clampSelection();
        if (listSelectedIndex >= planeCount || listSelectedIndex < 0) listSelectedIndex = planeCount > 0 ? constrain(listSelectedIndex, 0, planeCount - 1) : 0;

        // Re-anchor the detail view by ICAO hex
        if (currentScreen == SCR_PLANE_DETAIL && detailPlaneHex[0] != '\0') {
            int idx = -1;
            for (int i = 0; i < planeCount; i++) {
                if (planes[i].valid && strncmp(planes[i].icaoHex, detailPlaneHex, 7) == 0) { idx = i; break; }
            }
            if (idx < 0) currentScreen = SCR_RADAR;
            else detailPlaneIndex = idx;
        } else if (detailPlaneIndex >= planeCount) {
            detailPlaneIndex = planeCount > 0 ? planeCount - 1 : -1;
        }

        switch (currentScreen) {
            case SCR_RADAR: {
                int ez = effectiveZoom();
                RadarDisplay::renderRadar(planes, planeCount, sweepAngle, selectedPlaneIndex,
                                           ApiProviders::ZOOM_KM[ez], s.labelsMode, s.showSweepAnim,
                                           ApiProviders::getStatus());
                if (s.showSweepAnim) sweepAngle = (sweepAngle + 4) % 360;
                break;
            }
            case SCR_PLANE_DETAIL:
                if (detailPlaneIndex >= 0 && detailPlaneIndex < planeCount) {
                    RadarDisplay::renderPlaneDetail(planes[detailPlaneIndex], detailScrollY);
                } else {
                    currentScreen = SCR_RADAR;
                }
                break;
            case SCR_PLANE_LIST:
                RadarDisplay::renderPlaneList(planes, planeCount, listSelectedIndex);
                break;
            case SCR_SETTINGS_MAIN: {
                char labels[SETTINGS_MAIN_COUNT][24];
                const char* ptrs[SETTINGS_MAIN_COUNT];
                for (int i = 0; i < SETTINGS_MAIN_COUNT; i++) ptrs[i] = settingsMainLabels[i];
                snprintf(labels[0], 24, "Range: %d km%s", (int)ApiProviders::ZOOM_KM[s.zoomLevel], s.autoRange ? " A" : "");
                snprintf(labels[1], 24, "Auto Range: %s", s.autoRange ? "ON" : "OFF");
                snprintf(labels[2], 24, "Brightness: %d%%", s.brightness);
                snprintf(labels[3], 24, "Anim: %s", s.showSweepAnim ? "ON" : "OFF");
                const char* lm = s.labelsMode == 0 ? "OFF" : (s.labelsMode == 1 ? "SELECTED" : "ALL");
                snprintf(labels[4], 24, "Labels: %s", lm);
                const char* iconName = s.aircraftIcon == 0 ? "DOTS" : (s.aircraftIcon == 1 ? "ARROW" : "PLANE");
                snprintf(labels[5], 24, "Icon: %s", iconName);
                snprintf(labels[6], 24, "Theme: %s", THEME_NAMES[s.theme]);
                snprintf(labels[7], 24, "Compass: %s", s.showCompass ? "ON" : "OFF");
                snprintf(labels[8], 24, "Range Labels: %s", s.showRangeLabels ? "ON" : "OFF");
                snprintf(labels[9], 24, "Trail: %s", s.showTrail ? "ON" : "OFF");
                for (int i = 0; i <= 9; i++) ptrs[i] = labels[i];
                RadarDisplay::renderScrollMenu("SETTINGS", ptrs, SETTINGS_MAIN_COUNT, settingsMainIndex, settingsMainScroll);
                break;
            }
            case SCR_SETTINGS_BRIGHTNESS:
                RadarDisplay::renderBrightnessMenu(s.brightness);
                break;
            case SCR_SETTINGS_DISPLAY:
                RadarDisplay::renderScrollMenu("RADAR RANGE", settingsDisplayLabels, SETTINGS_DISPLAY_COUNT, settingsDisplayIndex, 0);
                break;
            case SCR_SETTINGS_LABELS:
                RadarDisplay::renderScrollMenu("LABELS", settingsLabelsLabels, SETTINGS_LABELS_COUNT, settingsLabelsIndex, 0);
                break;
            case SCR_SETTINGS_ICON:
                RadarDisplay::renderScrollMenu("AIRCRAFT ICON", settingsIconLabels, SETTINGS_ICON_COUNT, settingsIconIndex, 0);
                break;
            case SCR_SETTINGS_PROVIDERS: {
                char labels[SETTINGS_PROVIDERS_COUNT][24];
                const char* ptrs[SETTINGS_PROVIDERS_COUNT];
                for (int i = 0; i < SETTINGS_PROVIDERS_COUNT; i++) {
                    if (i < PROVIDER_COUNT) {
                        snprintf(labels[i], 24, "%s [%s]", settingsProvidersLabels[i], s.providerEnabled[i] ? "ON" : "OFF");
                        ptrs[i] = labels[i];
                    } else {
                        ptrs[i] = settingsProvidersLabels[i];
                    }
                }
                RadarDisplay::renderScrollMenu("PROVIDERS", ptrs, SETTINGS_PROVIDERS_COUNT, settingsProvidersIndex, settingsProvidersScroll);
                break;
            }
            case SCR_SYSTEM_INFO:
                RadarDisplay::renderSystemInfo(
                    WifiManager::getState() == WIFI_STATE_CONNECTED ? WifiManager::getStaIp() : WifiManager::getApIp(),
                    s.staSsid.length() > 0 ? s.staSsid : "(setup mode)"
                );
                break;
            case SCR_WEATHER:
                RadarDisplay::renderWeatherScreen();
                break;
            case SCR_FACTORY_RESET_CONFIRM:
                RadarDisplay::renderFactoryResetConfirm();
                break;
            default: break;
        }
    }

    // Radar screen is canvas/SPI directly — LVGL only needs servicing on the
    // menu/detail/weather screens.
    if (currentScreen != SCR_RADAR) {
        lv_timer_handler();
    }
    delay(5);
}

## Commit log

2026-09-06 Initial commit: FlyRadar32 v2.0.0 — ESP32 ADS-B radar firmware
    ESP32 + ST7735 1.8in radar display with 3-button UI, multi-provider
    ADS-B data (airplanes.live, adsb.lol), captive-portal Wi-Fi setup and
    a web management UI. Includes bugfix pass: fetch status flag, settings
    mutex scope, squawk/altitude parsing, JSON buffer sizing, Wi-Fi
    self-heal reconnect, detail-screen ICAO tracking, web UI fixes.
    [api_providers.cpp, config.h, main.cpp]
2026-09-06 docs: project-grade README (features, wiring diagram, roadmap, honest limitations); add MIT license
2026-09-12 fix: crush heap OOM crash + map overlay + tactical blip + WiFi scan/connect restored
    - webui.cpp: Replace DynamicJsonDocument(12288) in /api/aircraft with zero-heap static
    char[8192] serializer — eliminates AsyncWebServerResponse addHeader OOM crash
    - app.js: Replace aeroplane silhouette glyph with tactical radar diamond blip + heading tick
    - app.js: Restore missing WiFi scan (Scan btn) and connect (Connect Wi-Fi btn) handlers
    - app.js: Add real map tile overlay (OpenStreetMap) behind radar scope, toggled by Map btn
    - index.html: Add Map toggle button to radar toolbar
    - index.html: Remove Aeroplane Silhouette from icon selector dropdown
    - style.css: Add .net-item / .network-list CSS for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
    [api_providers.cpp, config.h, main.cpp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]
2026-09-12 fix: remove aeroplane icon from web radar — use clean ATC radar blip + heading tick
2026-09-12 fix: BACKLIGHT_ACTIVE_LOW false — brightness slider now works correctly (100% = full bright)
    [radar_display.cpp]
2026-09-12 Fix boot loops, LEDC brightness, OpenSky OAuth/credentials upload, and UI stability
    [api_providers.cpp, main.cpp, radar_display.cpp]
2026-09-12 Relocate radar zoom controls to side-bottom footer off scope, pure green theme, unified settings cards, and provider switching
2026-09-12 Fix continuous ESP32 auto-reboot: eliminate AsyncTCP header allocation aborts, stream JSON directly, bind AsyncTCP to Core 0 with 8KB stack, and add 429 rate limit backoff
    [api_providers.cpp]
2026-09-12 WIP: current uncommitted state before full issue audit fixes
    [api_providers.cpp, config.h, main.cpp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]
2026-09-12 Fix full issue-audit findings: wifi reconnect, fetch races, trail corruption, XSS, PIN removal, repo hygiene
    - wifi_manager: debounce connection-drop detection (5s) before reconnect
    - api_providers: first cycle runs immediately after boot; refreshRequested
    consumed under mutex (no lost refreshes); adsb.lol now HTTPS via shared
    v2-schema fetch (120 duplicated lines removed); 429 backoff hits the
    rate-limited provider, not a hardcoded index; JSON doc sized 6KB
    - storage: AIRCRAFT_ICON_PLANE selectable (clamp was stuck at ARROW);
    factoryReset holds settings mutex; PIN lock removed entirely
    - webui: request body cap 4KB; primary-provider switch preserves the
    user's enable/disable flags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
    [api_providers.cpp, config.h, main.cpp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]
2026-09-12 Silence NVS 'pin NOT_FOUND' log on fresh devices (check isKey before remove)
2026-09-12 Add hardware watchdog: 15s esp_task_wdt on main loop, panic-reboot on hang
    [config.h, main.cpp]
2026-09-12 Async Wi-Fi scan: start+poll endpoint, never blocks async_tcp thread; app.js polls every 800ms
2026-09-12 Bearing-sorted cursor: planes sorted by compass bearing each fetch; UP/DOWN walks clockwise; selection re-anchored by ICAO hex
2026-09-12 Auto-range: device picks zoom fitting 10th-closest aircraft (2-cycle hysteresis); settings toggle on device + web; manual pick disables auto
2026-09-12 Radar screen modernization: scope canvas on 0x0E1116 bg with hairline frame, LVGL floating sidebar card (status/TGT/range/telemetry rows, Montserrat, theme accent)
2026-09-12 Revert "Radar screen modernization: scope canvas on 0x0E1116 bg with hairline frame, LVGL floating sidebar card (status/TGT/range/telemetry rows, Montserrat, theme accent)"
    This reverts commit 5575e6e2b7a6f246409ff435e9d9ed91b824c797.
    [radar_display.cpp]
2026-09-12 Radar revert follow-ups: canvas-only radar loop (LVGL guarded off radar), watchdog via existing TWDT (no re-init log spam), clearLVGL on weather card entry, adsb schema doc 10KB
    [api_providers.cpp, config.h, main.cpp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]
2026-09-13 feat(enclosure): add parametric OpenSCAD 3D printable desktop ATC enclosure and STLs
    [flyradar32_bottom.stl, flyradar32_buttons.stl, flyradar32_case.scad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]
2026-09-13 Calibrate 3D enclosure with physical clone CAD files for TFT, ESP32, and tactile switch
    [AZ-Delivery 1.8 inch TFT Display SPI.stp, esp32_30pin_CH340.SLDPRT, flyradar32_bottom.stl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]
2026-09-13 Redesign enclosure: sleek low-profile desktop console with zero face screws and flush buttons
    [flyradar32_bottom.stl, flyradar32_buttons.stl, flyradar32_case.scad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]
2026-09-13 Convert all enclosure and component 3D CAD files to ISO 10303-21 STEP (.stp) format
    [esp32_30pin_CH340.stl, esp32_30pin_CH340.stp, flyradar32_bottom.stp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]
2026-09-13 feat(enclosure): complete FlyRadar32 console re-engineering with snap-fit ESP32 cradle, wall-supported button carrier, precision display aperture, and production STLs
    [FlyRadar32_Enclosure.FCStd, esp32_30pin_CH340.SLDPRT, esp32_30pin_CH340.stl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]
2026-09-13 feat(enclosure): modernize industrial console styling with sun-visor bezel, button dishes, debossed glyphs, angled louvers, and grip flutes
    [FlyRadar32_Enclosure.FCStd, flyradar32_lid.stl, flyradar32_shell.stl]
2026-09-13 feat(enclosure): add +0.25mm extra clearances for ESP32 body, Type-C cable shroud relief pocket, and 0.35mm lid sliding fit
    [FlyRadar32_Enclosure.FCStd, flyradar32_lid.stl, flyradar32_shell.stl]
2026-09-13 fix(enclosure): align display aperture to exact active matrix center and center Type-C port vertically at Z=5.725mm
    [FlyRadar32_Enclosure.FCStd, flyradar32_lid.stl, flyradar32_shell.stl]
2026-09-13 feat(enclosure): seamless joint, 45-deg continuous support ledge, screwless snap assembly (20/20 checks 0mm3)
    [FlyRadar32_Enclosure.FCStd, flyradar32_lid.stl, flyradar32_shell.stl]
2026-09-13 fix(enclosure): eliminate floating skirt, solid 45-deg support joint, zero-support 3D print ready
    [FlyRadar32_Enclosure.FCStd, flyradar32_lid.stl, flyradar32_shell.stl]
2026-09-13 feat(enclosure): 100% screwless console - push-and-set TFT snap cradle, zero corner screw posts, toolless removal (20/20 PASS 0mm3)
    [FlyRadar32_Enclosure.FCStd, flyradar32_lid.stl, flyradar32_shell.stl]
2026-09-15 feat(enclosure): restore 4-corner TFT standoffs, printable solid button caps, and export deliverables
    [FlyRadar32_Enclosure.FCStd, flyradar32_button_caps.stl, flyradar32_console_multicolor.3mf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]
2026-09-15 fix(enclosure): align ESP32 shell locator pins with exact STEP model hole positions
    [FlyRadar32_Enclosure.FCStd, flyradar32_console_multicolor.3mf, flyradar32_lid_multicolor.3mf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]
2026-09-15 fix(enclosure): align ESP32 locator pins and lower USB-C cutout to eliminate ledge collision
    [FlyRadar32_Enclosure.FCStd, flyradar32_console_multicolor.3mf, flyradar32_lid_multicolor.3mf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]
2026-09-15 fix(enclosure): universal ESP32 cradle matching CH340 and WROOM boards with zero collision
    [FlyRadar32_Enclosure.FCStd, esp32_30pin_CH340.STEP, flyradar32_console_multicolor.3mf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]
2026-09-15 fix(enclosure): eliminate thin Type-C bottom bridge and align 4 ESP32 pillars to CH340 board
    [FlyRadar32_Enclosure.FCStd, flyradar32_console_multicolor.3mf, flyradar32_lid_multicolor.3mf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]
2026-09-15 fix(enclosure): clean simple Type-C port opening and 100% solid flat bottom plate
    [FlyRadar32_Enclosure.FCStd, flyradar32_console_multicolor.3mf, flyradar32_lid_multicolor.3mf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]
2026-09-18 feat(enclosure): 15 deg ergonomic tilt, smooth bottom shell, reinforced internal snaps, right-sized Type-C port, and sleek red top accents
    [FlyRadar32_Enclosure.FCStd, flyradar32_console_multicolor.3mf, flyradar32_lid.stl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]
2026-09-19 feat: finalize reinforced button caps, enclosure STLs, and firmware updates
    [FlyRadar32_Enclosure.FCStd, flyradar32_button_caps.stl, flyradar32_console_multicolor.3mf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]
2026-09-19 feat: implement hardware PWM backlight brightness control on TFT and Web Dashboard
2026-09-19 fix: route button events to handleSettingsButtons for SCR_SETTINGS_BRIGHTNESS
    [main.cpp]
2026-09-19 refactor: open-source release cleanup, professional README, animated Ko-fi badge, and enclosure 3D files curation
    [AZ-Delivery 1.8 inch TFT Display SPI.stp, FlyRadar32_Enclosure.FCStd, esp32_30pin_CH340.STEP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]
2026-09-19 docs: add 3D enclosure renders and web dashboard visuals, streamline 3D print guide
2026-09-19 docs: integrate official circuit diagram, FreeCAD 3D enclosure renders, and full 4-tab web UI gallery
2026-09-19 docs: add live physical breadboard prototype photograph alongside circuit diagram
2026-09-19 docs: add upgraded animated Ko-fi badge on top and reformat prototype and schematic into dedicated sections
2026-09-19 docs: update README pinout, protective CC BY-NC-ND license, and refined web flasher tutorial
    [FlyRadar32_Enclosure.FCStd]
2026-09-20 feat: swap BTN_SELECT/DOWN pins, fix OpenSky SRC display, enable default map with 1.3x aircraft icon, and overhaul WiFi setup verification
    [api_providers.cpp, config.h]
2026-09-20 fix: expand maxRangeKm to 320km, increase MAX_PLANES to 50, add 300km button, and default web scope to 300km
    [api_providers.cpp, config.h]
2026-09-20 Fix JSON parse memory exhaustion by streaming directly from socket without String buffer
    [api_providers.cpp]
2026-09-20 feat: upgrade to esp-flasher-button with dynamic GitHub release resolution and red pill styling
2026-09-20 style: constrain blog wrapper width to 860px and use light theme with larger size for flasher button
2026-09-21 docs: replace CAD hero with live working hardware photo in README and blog
